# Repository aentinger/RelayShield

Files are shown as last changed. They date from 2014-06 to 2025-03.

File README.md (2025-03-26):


💾 Relay Shield
===============



# 📸 Image

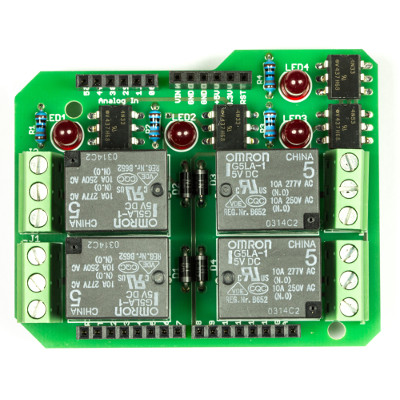
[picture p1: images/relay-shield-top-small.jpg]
LXRobotics P12 Relay Shield


# 📂 Description

The LXRobotics Relay Shield allows to independently switch up to different 4 loads. The switching of any relay is signalised by its own red status LED. High quality screw terminals ensure stable and durable connections. For an quick and easy start, a open source Arduino library with sample programs is available.

**Features**

* Potential-free switching of up to 4 different loads through 4 relays/contactors
* Max. current per relay: 10 A
* Max. voltage DC per relay: 24 V DC
* Max voltage AC per relay: 250 V AC
* Relay type: SPDT (Single Pole commutator)
* Red LED's shows relay status (ON/OFF)
* Optocouplers used to isolate relay circuit from Arduino 
* High quality screw terminals
* Arduino Library with example programs is available on GitHub

# 🎥 [Video](images/relay_shield_demo.mp4)

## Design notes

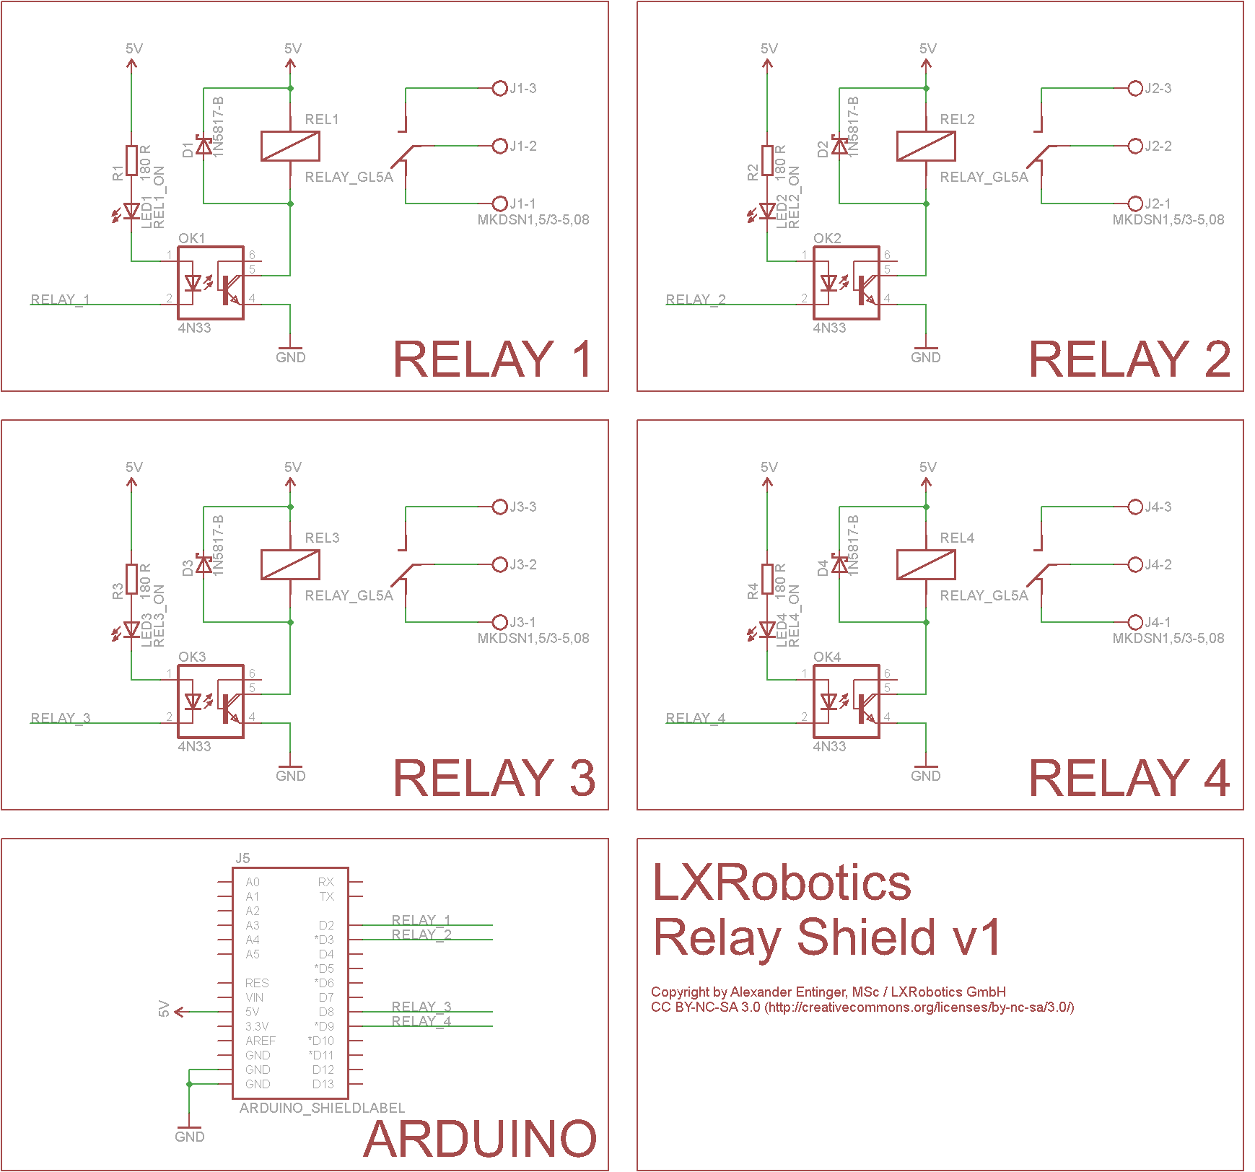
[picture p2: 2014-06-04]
hardware/lxr_relay_shield_v1.png

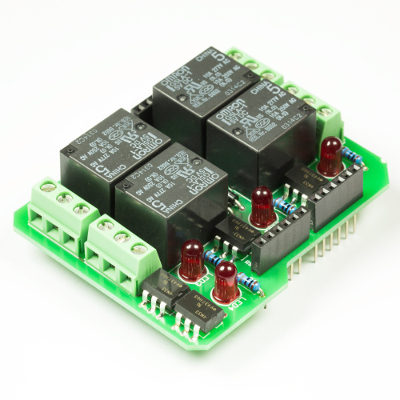
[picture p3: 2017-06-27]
images/relay-shield-side-small.jpg

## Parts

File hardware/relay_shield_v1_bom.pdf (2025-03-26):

Menge | Schaltplan | Bezeichnung | Farnell Bestell Nummer | Preis (1 Stück) | Gesamtpreis | Wird bestückt | Footprint | Säckchen | ESD
4 | REL1,REL2,REL3,REL4 | GL5A Leistungsrelais, 5 VDC, 250 V AC, 10 A, RCOIL = 70 R | 1455502 | € 1,43 | € 5,72 | | | S1
4 | OK1,OK2,OK3,OK4 | 4N33, Optokoppler mit Photo-Darlington, DIL06 | 1469601 | € 0,45 | € 1,79 | | | S2 | x
4 | D1,D2,D3,D4 | 1N5817, Diode Shottkey, If=1A, Ur=20V | 1458990 | € 0,30 | € 1,19 | | | S3 | x
4 | LED1,LED2,LED3,LED4 | LED Rot, 5 mm, Uf=1.9V, If=10 mA | 1660489 | € 0,35 | € 1,39 | | | S2 | x
4 | R1,R2,R3,R3 | Widerstand, 180 R, 0.25 W | 9341420 | € 0,02 | € 0,09 | | | S3 | x
4 | J1,J2,J3,J4 | Schraubklemme 3-Polig, MKDSN1.5/3-5.08 | 3041451 | € 1,42 | € 5,68 | | | S1
1 | J5 | Satz Arduino Buchsenleisten | ELV | € | 0,75 | € | 0,75 | - | http://www.elv.at/buchsenleisten-set-fuer-arduino-boards.html
1 | | Leitfähiger Schaumstoff | 1687855 | € | 2,40 | € | 2,40 | - | Bestellung von 1 Stück für 50 Relay Shields ausreichend
| | | | Summe | | € | 19,01

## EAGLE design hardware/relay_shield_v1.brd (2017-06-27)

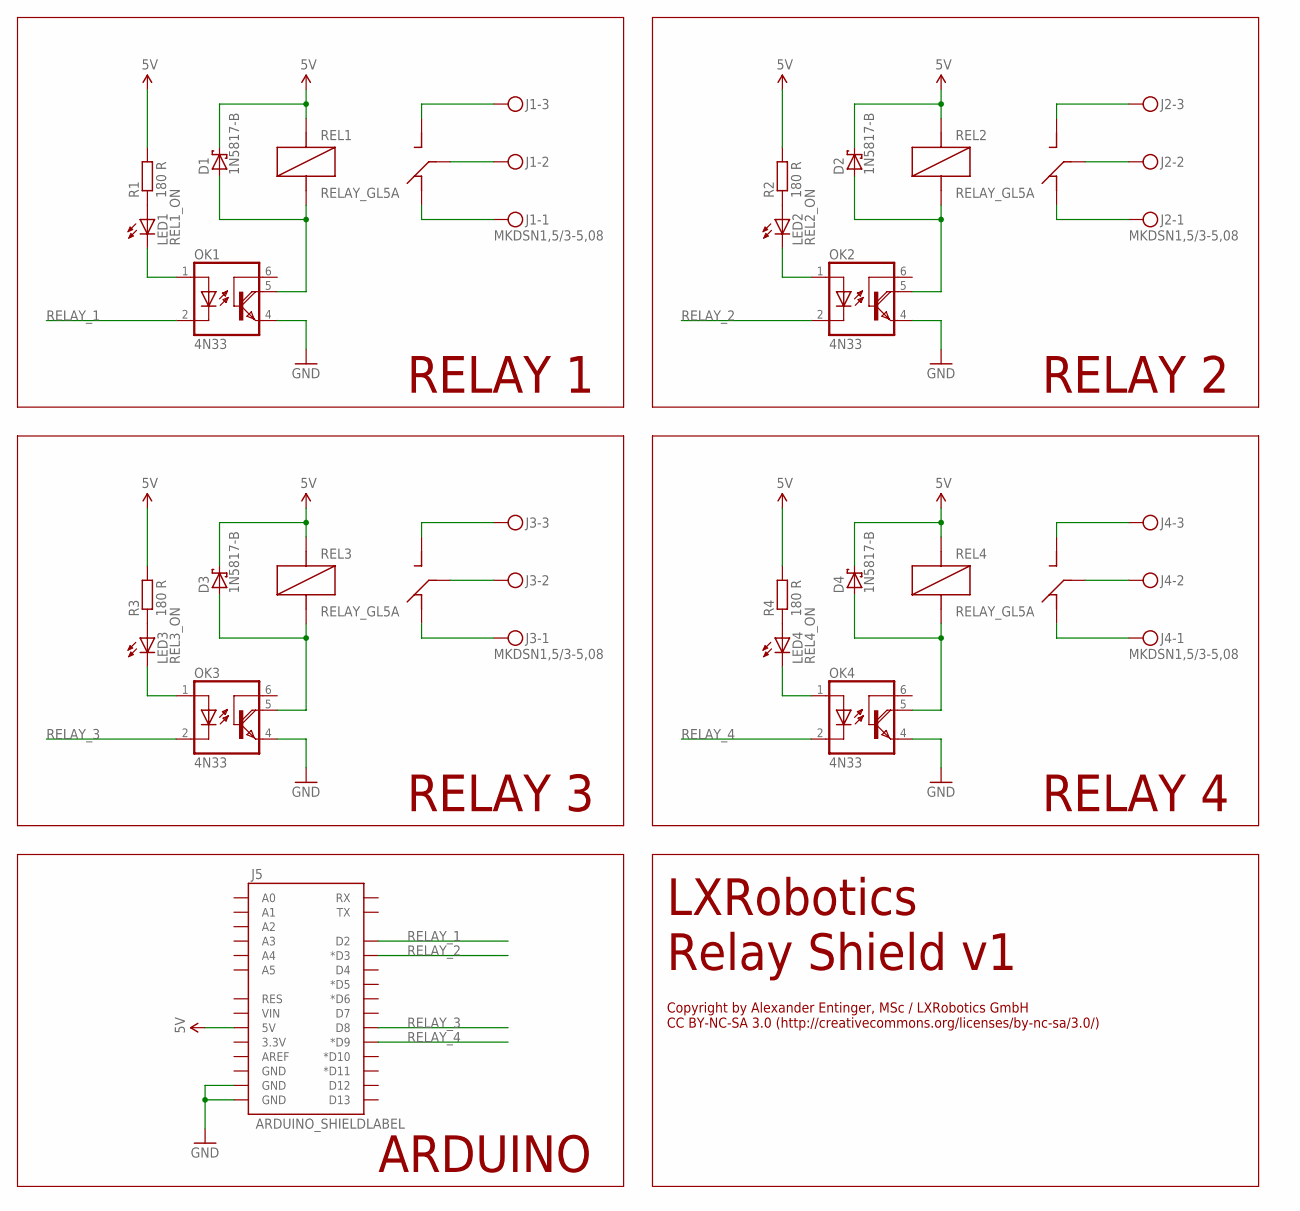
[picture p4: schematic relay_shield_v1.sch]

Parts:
D1, D2, D3, D4: 1N5817-B; DO41-7.6
J1, J2, J3, J4: MKDSN1,5/3-5,08
J5: ARDUINO_SHIELDLABEL; DUEMILANOVE_SHIELD
LED1: REL1_ON; LED5MM
LED2: REL2_ON; LED5MM
LED3: REL3_ON; LED5MM
LED4: REL4_ON; LED5MM
OK1, OK2, OK3, OK4: 4N33; DIL06
R1, R2, R3, R4: 180 R; 0204/7
REL1, REL2, REL3, REL4: RELAY_GL5A

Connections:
5V: D1.C, D2.C, D3.C, D4.C, J5.5V, R1.2, R2.2, R3.2, R4.2, REL1.R2 (R2_COIL1), REL2.R2 (R2_COIL1), REL3.R2 (R2_COIL1), REL4.R2 (R2_COIL1)
GND: J5.GND@0 (GND), J5.GND@1 (GND), OK1.4 (E), OK2.4 (E), OK3.4 (E), OK4.4 (E)
unnamed: D1.A, OK1.5 (COL), REL1.R5 (R5_COIL2)
unnamed: J1.2, REL1.R1 (R1_COMMON)
unnamed: J1.1, REL1.R4 (R4_SW)
unnamed: LED1.K (C), OK1.1 (A)
unnamed: LED1.A, R1.1
unnamed: J1.3, REL1.R3 (R3_SW)
unnamed: D2.A, OK2.5 (COL), REL2.R5 (R5_COIL2)
unnamed: LED2.K (C), OK2.1 (A)
unnamed: LED2.A, R2.1
unnamed: J2.2, REL2.R1 (R1_COMMON)
unnamed: J2.1, REL2.R4 (R4_SW)
unnamed: J2.3, REL2.R3 (R3_SW)
unnamed: D3.A, OK3.5 (COL), REL3.R5 (R5_COIL2)
unnamed: LED3.K (C), OK3.1 (A)
unnamed: LED3.A, R3.1
unnamed: J3.2, REL3.R1 (R1_COMMON)
unnamed: J3.1, REL3.R4 (R4_SW)
unnamed: J3.3, REL3.R3 (R3_SW)
unnamed: D4.A, OK4.5 (COL), REL4.R5 (R5_COIL2)
unnamed: LED4.K (C), OK4.1 (A)
unnamed: LED4.A, R4.1
unnamed: J4.2, REL4.R1 (R1_COMMON)
unnamed: J4.1, REL4.R4 (R4_SW)
unnamed: J4.3, REL4.R3 (R3_SW)
RELAY_1: J5.D2, OK1.2 (C)
RELAY_2: J5.D3 (*D3), OK2.2 (C)
RELAY_3: J5.D8, OK3.2 (C)
RELAY_4: J5.D9 (*D9), OK4.2 (C)

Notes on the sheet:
RELAY 1
RELAY 2
RELAY 3
RELAY 4
ARDUINO
LXRobotics Relay Shield v1
Copyright by Alexander Entinger, MSc / LXRobotics GmbH CC BY-NC-SA 3.0 (http://creativecommons.org/licenses/by-nc-sa/3.0/)

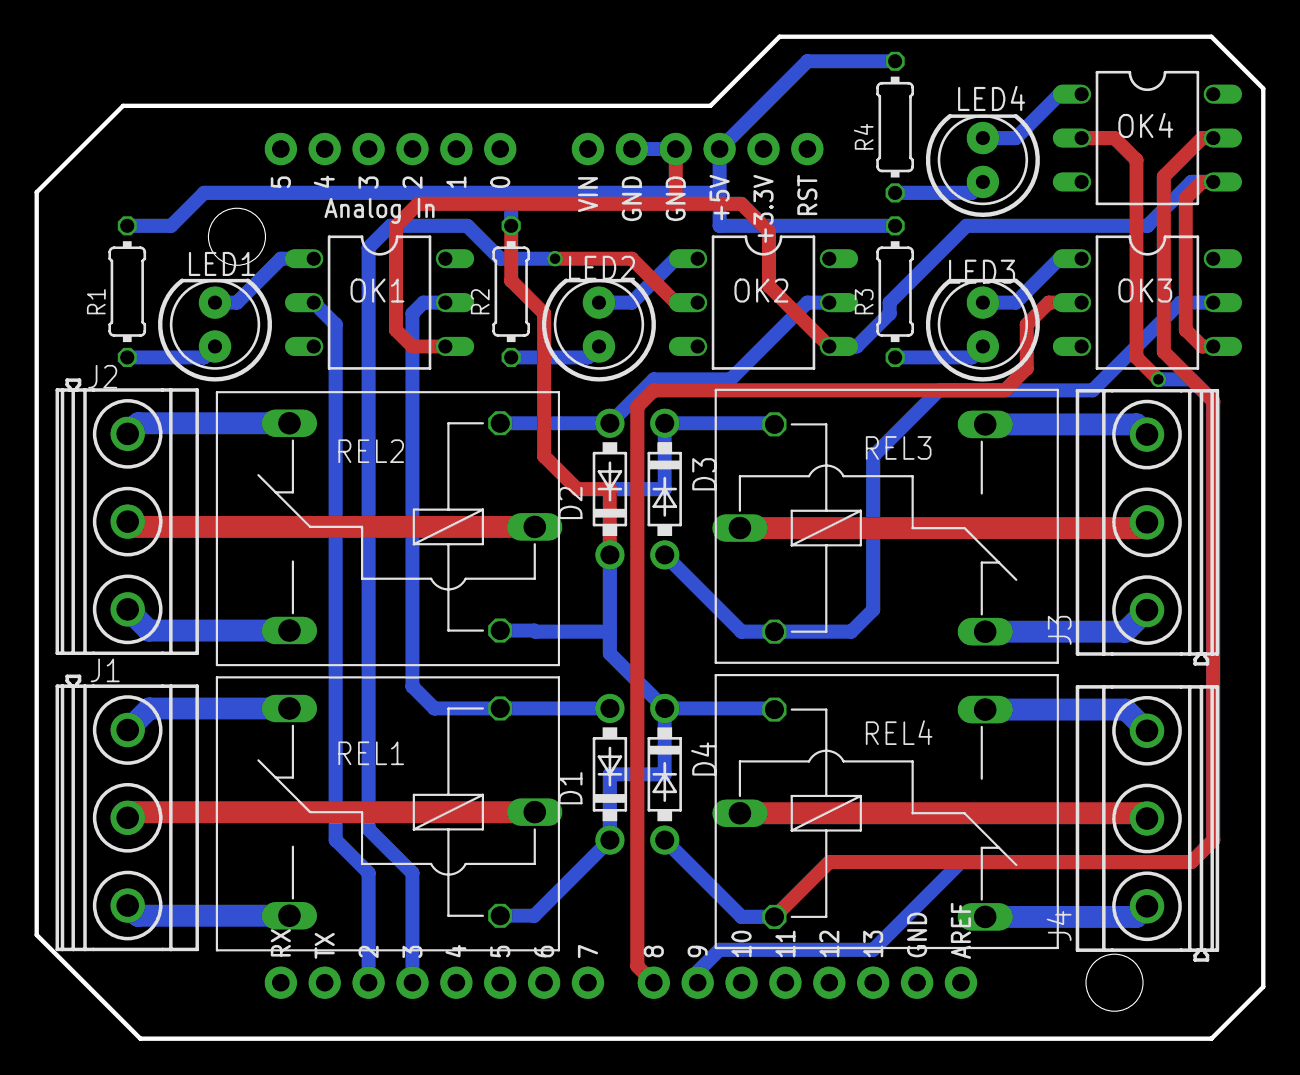
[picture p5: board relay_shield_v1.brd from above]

Board: 2 copper layers, 71.0 x 58.0 mm, 25 parts (0 on the bottom side), 30 nets.

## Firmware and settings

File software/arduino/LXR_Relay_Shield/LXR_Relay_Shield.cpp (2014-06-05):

/**
 * @author Alexander Entinger, MSc / LXRobotics
 * @brief this module implements the library for controlling the LXRobotics Relay Shield
 * @file LXR_Relay_Shield.cpp
 * @license Attribution-NonCommercial-ShareAlike 3.0 Unported (CC BY-NC-SA 3.0) ( http://creativecommons.org/licenses/by-nc-sa/3.0/ )
 */

#include "LXR_Relay_Shield.h"

static int const RELAY_1_PIN = 2;
static int const RELAY_2_PIN = 3;
static int const RELAY_3_PIN = 8;
static int const RELAY_4_PIN = 9;

/**
 * @brief initializes the LXR_Relay_Shield library
 */
void LXR_Relay_Shield::begin() {
  pinMode(RELAY_1_PIN, OUTPUT);
  pinMode(RELAY_2_PIN, OUTPUT);
  pinMode(RELAY_3_PIN, OUTPUT);
  pinMode(RELAY_4_PIN, OUTPUT);
  LXR_Relay_Shield::turn_off(REL1);
  LXR_Relay_Shield::turn_off(REL2);
  LXR_Relay_Shield::turn_off(REL3);
  LXR_Relay_Shield::turn_off(REL4);
}

/**
 * @brief turn a speficic relay on
 */
void LXR_Relay_Shield::turn_on(E_RELAY_SELECT const sel) {
  switch(sel) {
   case REL1: digitalWrite(RELAY_1_PIN, LOW); break; 
   case REL2: digitalWrite(RELAY_2_PIN, LOW); break;
   case REL3: digitalWrite(RELAY_3_PIN, LOW); break;
   case REL4: digitalWrite(RELAY_4_PIN, LOW); break;
   default: break;
  }
}

/**
 * @brief turn a speficic relay off
 */
void LXR_Relay_Shield::turn_off(E_RELAY_SELECT const sel) {
  switch(sel) {
   case REL1: digitalWrite(RELAY_1_PIN, HIGH); break; 
   case REL2: digitalWrite(RELAY_2_PIN, HIGH); break;
   case REL3: digitalWrite(RELAY_3_PIN, HIGH); break;
   case REL4: digitalWrite(RELAY_4_PIN, HIGH); break;
   default: break;
  }  
}

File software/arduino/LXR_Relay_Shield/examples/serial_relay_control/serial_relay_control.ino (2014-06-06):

/**
 * @author Alexander Entinger, MSc / LXRobotics
 * @brief this sketch demonstrates how the 4 relay of the LXRobotics Relay Shield can be controlled via a simple serial protocol
 * @file serial_relay_control.ino
 */

// PROTOCOL Description
// Turn Relay 1 on -> 'R11'
// Turn Relay 1 off -> 'R10'
// Turn Relay 2 on -> 'R21'
// Turn Relay 2 off -> 'R20'
// 3 Byte Protcol = [START_SIGN, RELAY_SELECTION, RELAY_STATE]
// Start Sign = 'R'
// Relay Selection = '1' | '2' | '3' | '4'
// Relay State = '0' (OFF) | '1' (ON)

 
#include "LXR_Relay_Shield.h"
 
void setup() {
  LXR_Relay_Shield::begin();
  Serial.begin(115200);
}
 
void loop() {
  while(Serial.available() > 0) {
   byte const received_byte =  Serial.read();
   parse_byte(received_byte);
  }
}

void parse_byte(char const b) {
  typedef enum {START=0, RELAY_NUMBER=1, RELAY_STATE=2} E_PARSE_STATE;
  static E_PARSE_STATE state = START;
  static E_RELAY_SELECT relay_number = REL1;

  switch(state) {
   case START: {
     state = RELAY_NUMBER;
   } break;
   case RELAY_NUMBER: {
     if(b == 'R') state = START;
     else state = RELAY_STATE;

     switch(b) {
      case '1': relay_number = REL1; break;
      case '2': relay_number = REL2; break;
      case '3': relay_number = REL3; break;
      case '4': relay_number = REL4; break;
      default: state = START; break;
     }
   } break;
   case RELAY_STATE: {
     if(b == '0') LXR_Relay_Shield::turn_off(relay_number);
     else if(b == '1') LXR_Relay_Shield::turn_on(relay_number);
     if(b == '0' || b == '1') Serial.println("ACK");
     else Serial.println("NOT ACK");
     state = START;
   } break;
   default: break;
  }
}

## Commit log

2014-06-04 initial checkin of relay shield files
2014-06-05 turns all relays off now at initialization of library
2014-06-06 adding beatbox and serial relay control examples
2014-06-06 inserted small protcol documentation into serial_relay_control.ino
2017-06-27 Adding hardware + images
    [relay_shield_v1.brd, relay_shield_v1.sch]
2025-03-26 Add BOM.

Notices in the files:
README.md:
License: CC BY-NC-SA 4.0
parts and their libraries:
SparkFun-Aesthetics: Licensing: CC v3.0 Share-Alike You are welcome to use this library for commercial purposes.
